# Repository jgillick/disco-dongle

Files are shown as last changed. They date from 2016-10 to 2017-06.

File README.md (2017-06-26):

# Disco Dongle

Open Source Hardware (http://www.oshwa.org/)

A USB to RS485 dongle uniquely designed for [Disco Bus](https://github.com/jgillick/Disco-Bus-Protocol)
networks, however, can be used for many other multidrop needs.

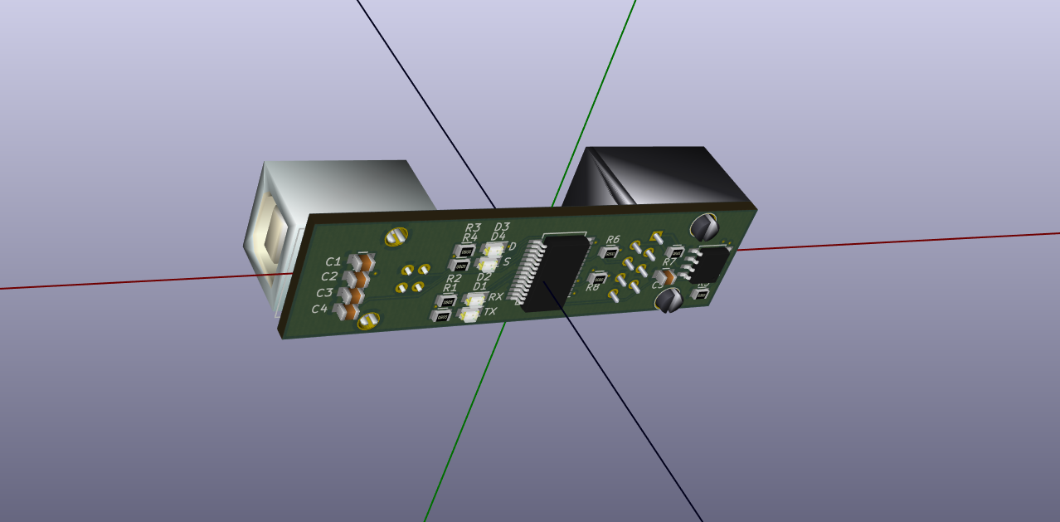
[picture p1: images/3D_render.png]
3D Rendering


## About

This is a basic FTDI to RS485 device, that will connect your computer to a multidrop
network via USB. The RTS line is connected to RJ45 jack (ethernet jack) pin 3, and the DSR line is
connected to RJ45 jack pin 4.

If using this on a Disco Bus network, RTS/pin 3 would be to the first node's daisy chain line and
DSR/ping 4 would be on the shared signal line.

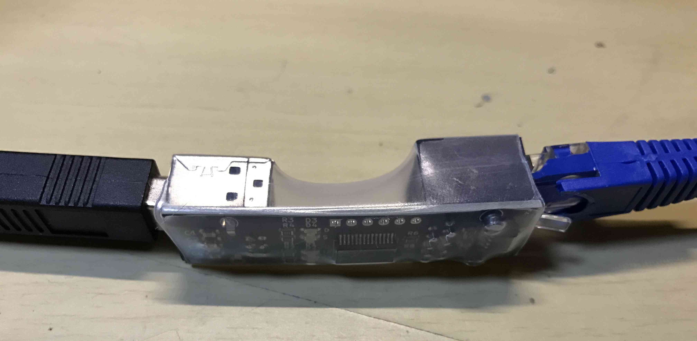
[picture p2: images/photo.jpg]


## Ethernet Pinout

The output of the dongle to the bus, is via a RJ45 ethernet jack.

| RJ45 Pin | Connection |
|---|---|
| 1 | RS485 A/Y |
| 2 | RS485 B/Z |
| 3 | RTS / Daisy |
| 4 | DSR / Signal  |
| 5 | GND |
| 6 | GND |
| 7 | Not connected |
| 8 | Not connected |

### RTS & DSR Lines

The `RTS` and `DSR` serial lines are broken out to RJ45 pins 3 and 4, respectively.
They are pulled up by a pair of 20k resistors, and assumed enabled when driven low.
They also have LEDs used to determine their enabled state. The LED for `RTS` is labeled
"D" (for Daisy) and `DSR` is labeled "S" (for Signal).

## Power over the bus

Since pins 7 and 8 are unused, these can be used to send power to the bus, while
using pins 5 and 6 for ground.

## BOM

| QTY | Designator  | Value | Footprint | Description | Digikey |
|-----|---|---|---|---|---|
| 4 | R1,R2,R4,R3 | 200 | 0805 | Resistor | [RMCF0805JT200RCT-ND](https://www.digikey.com/product-detail/en/stackpole-electronics-inc/RMCF0805JT200R/RMCF0805JT200RCT-ND/1942543) |
| 3 | R5,R6,R8 | 20k | 0805 | Resistor | [311-20KARCT-ND](https://www.digikey.com/product-detail/en/yageo/RC0805JR-0720KL/311-20KARCT-ND/731229) |
| 1 | R7 | 120 | 0805 | Resistor | [RMCF0805JT120R](http://www.digikey.com/product-detail/en/stackpole-electronics-inc/RMCF0805JT120R/RMCF0805JT120RCT-ND/1942540) |
| 3 | C1,C4,C5 | 100nF | 0805 | Capacitor | [1276-2450-1-ND](http://www.digikey.com/product-detail/en/samsung-electro-mechanics-america-inc/CL21B104MBCNNNC/1276-2450-1-ND/3890536) |
| 1 | C2 | 4.7uF | 0805 | Capacitor | [1276-6463-1-ND](http://www.digikey.com/product-detail/en/samsung-electro-mechanics-america-inc/CL21A475KOFNNNG/1276-6463-1-ND/5958091)|
| 1 | C3 | 10nF | 0805 | Capacitor | [1276-2434-1-ND](http://www.digikey.com/product-detail/en/samsung-electro-mechanics-america-inc/CL21B103KAANNNC/1276-2434-1-ND/3890520) |
| 2 | D1,D2 | | 0805 | TX/RX LEDs | [475-1415-1-ND](http://www.digikey.com/product-detail/en/osram-opto-semiconductors-inc/LH-R974-LP-1/475-1415-1-ND/1802604) |
| 2 | D3,D4 | | 0805 | Daisy/Signal LEDs | [475-1410-1-ND](http://www.digikey.com/product-detail/en/osram-opto-semiconductors-inc/LG-R971-KN-1/475-1410-1-ND/1802598) |
| 1 | U1 | | SSOP-28 | FT232RL | [768-1007-1-ND](http://www.digikey.com/product-detail/en/ftdi-future-technology-devices-international-ltd/FT232RL-REEL/768-1007-1-ND/1836402) |
| 1 | U2 | | SOIC-8 | RS485 Transceiver | [ISL81487EIBZ-TCT-ND](http://www.digikey.com/product-detail/en/intersil/ISL81487EIBZ-T/ISL81487EIBZ-TCT-ND/1034270) |
| 1 | J1 | | | USB - B Micro | [609-4618-1-ND](http://www.digikey.com/product-search/en?keywords=609-4618-1-ND) |
| 1 | J2 | | | RJ45 Jack | [609-1046-ND](http://www.digikey.com/product-search/en?keywords=54602-908LF) |

## Order One

You can either build one yourself, or [MacroFab](http://macrofab.com) will assemble
one for you for ~$30.

To use MacroFab:

 * [Create an account](http://macrofab.com)
 * Create a new PCB
 * Goto the "Design Files" tab.
   * Upload `BOM_MacroFab.xyrs`
   * Upload `Gerbers/*`
 * Goto the "Bill of Materials" tab and Verify all parts are selected/populated (except OSHW-Logo).
 * Goto the "Placement" tab and verify parts are arranged properly.
 * Click "Order Now"

## Credit

 This hardware was adapted from the [original work](https://github.com/cinderblock/DanceDongle)
 by [Cameron Tacklind](https://github.com/cinderblock).

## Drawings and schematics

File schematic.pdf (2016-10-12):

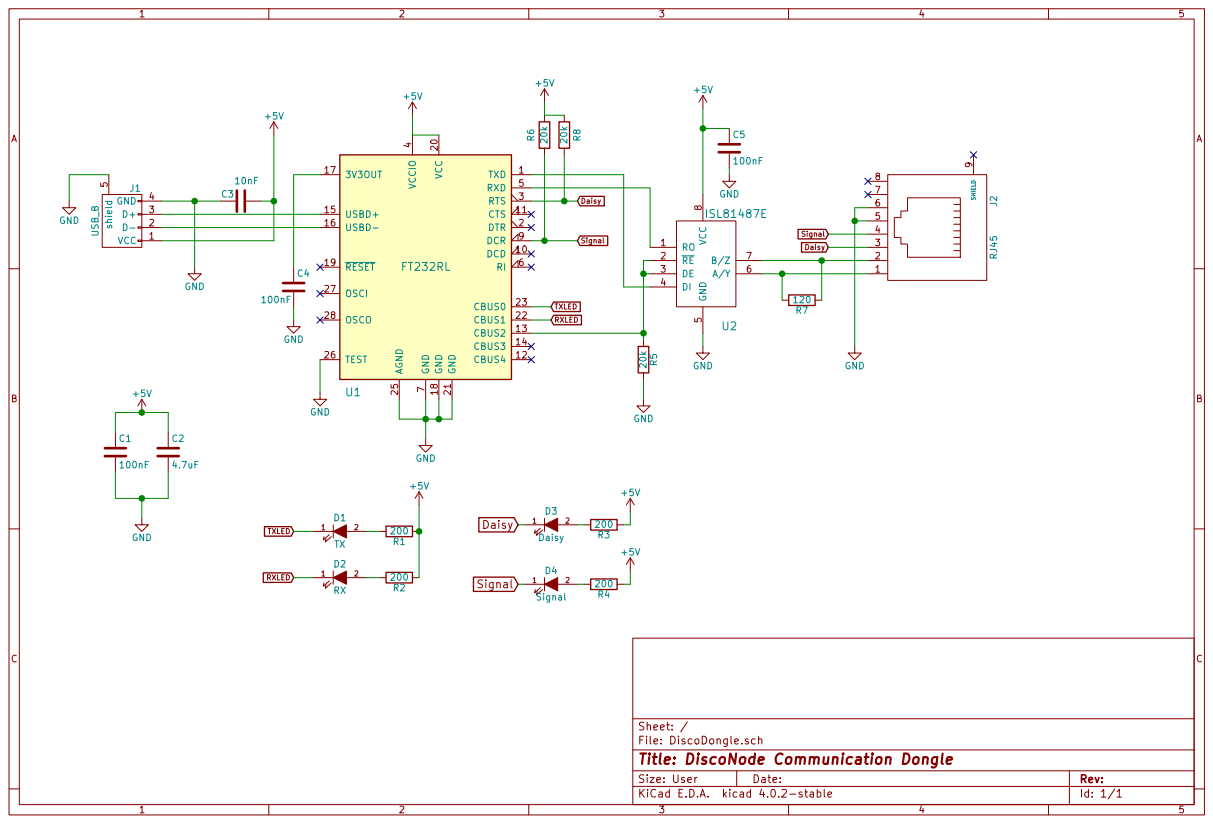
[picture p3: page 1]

7 DCR 9 DCD 10 VCC 20 CTS 11 GND 21 CBUS4 12 CBUS1 22 CBUS2 13 CBUS0 23 CBUS3 14 USBD+ 15 AGND 25 USBD- 16 TEST 26

File: DiscoDongle.sch Sheet: /
Id: 1/1 Title: DiscoNode Communication Dongle

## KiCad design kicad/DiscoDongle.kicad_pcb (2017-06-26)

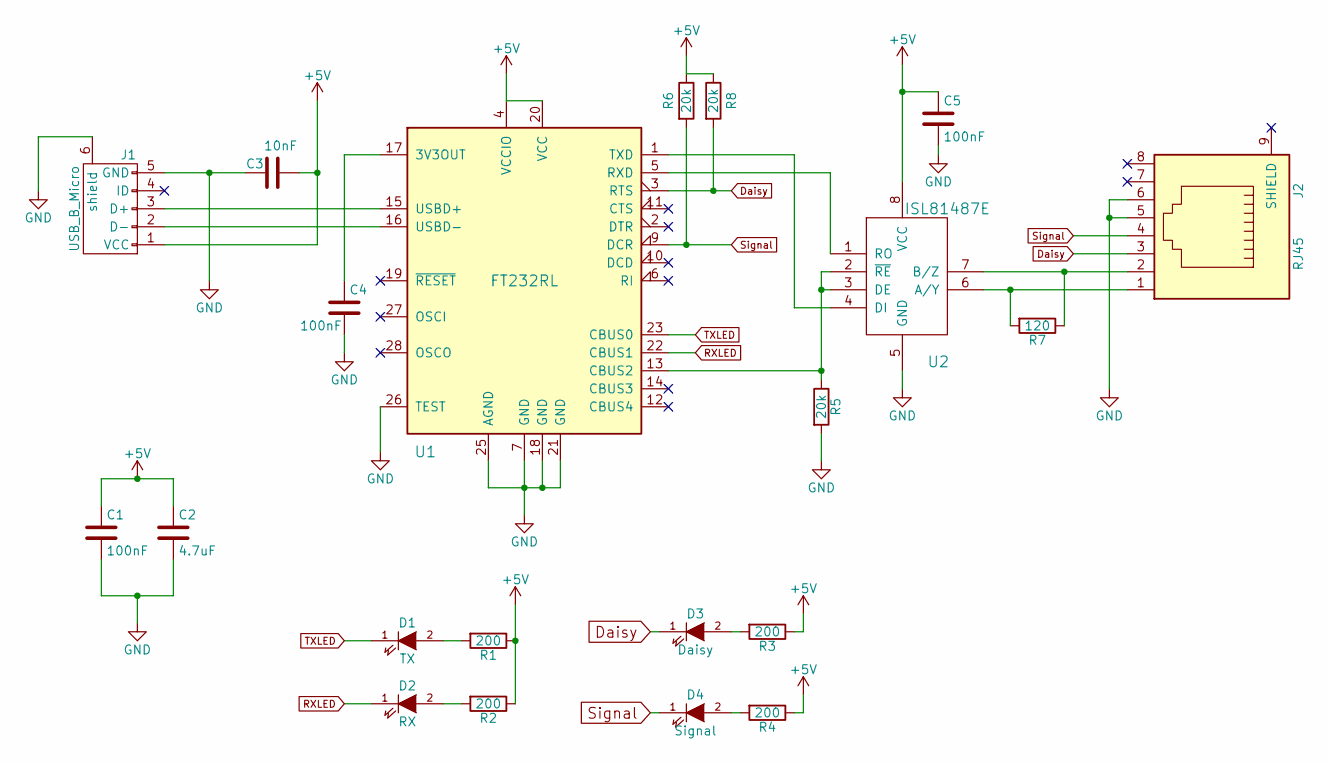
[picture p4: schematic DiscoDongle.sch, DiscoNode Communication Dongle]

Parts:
C1, C4, C5: 100nF; C_0805
C2: 4.7uF; C_0805; MPN CL21A475KOFNNNG; Digikey 1276-6463-1-ND
C3: 10nF; C_0805; MPN CL21B103KAANNNC; Digikey 1276-2434-1-ND
D1: TX; LED_0805; MPN LH R974-LP-1; Digikey 475-1415-1-ND
D2: RX; LED_0805; MPN LH R974-LP-1; Digikey 475-1415-1-ND
D3: Daisy; LED_0805; MPN LG R971-KN-1; Digikey 475-1410-1-ND
D4: Signal; LED_0805; MPN LG R971-KN-1; Digikey 475-1410-1-ND
J1: USB_B_Micro; USB_Micro-B; MPN 10118194-0001LF; Digikey 609-4618-1-ND
J2: RJ45; RJ45_8; MPN 54602-908LF; Digikey 609-1046-ND
R1, R2, R3, R4: 200; R_0805
R5, R6, R8: 20k; R_0805
R7: 120; R_0805; MPN RMCF0805JT120R; Digikey RMCF0805JT120RCT-ND
U1: FT232RL; SSOP-28_5.3x10.2mm_Pitch0.65mm; MPN FT232RL; Digikey 768-1007-1-ND
U2: ISL81487E; SOIC-8_3.9x4.9mm_Pitch1.27mm; Digikey ISL81487EIBZ-TCT-ND

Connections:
+5V: C1.1, C2.1, C3.1, C5.1, J1.1 (VCC), R1.1, R2.1, R3.1, R4.1, R6.1, R8.1, U1.4 (VCCIO), U1.20 (VCC), U2.8 (VCC)
Daisy: D3.1 (K), J2.3, R8.2, U1.3 (RTS)
GND: C1.2, C2.2, C3.2, C4.2, C5.2, J1.5 (GND), J1.6 (shield), J2.5, J2.6, R5.2, U1.7 (GND), U1.18 (GND), U1.21 (GND), U1.25 (AGND), U1.26 (TEST), U2.5 (GND)
unnamed: C4.1, U1.17 (3V3OUT)
unnamed: D1.2 (A), R1.2
unnamed: D2.2 (A), R2.2
unnamed: D3.2 (A), R3.2
unnamed: D4.2 (A), R4.2
unnamed: J1.2 (D-), U1.16 (USBD-)
unnamed: J1.3 (D+), U1.15 (USBD+)
unnamed: J2.1, R7.2, U2.6 (A/Y)
unnamed: J2.2, R7.1, U2.7 (B/Z)
unnamed: R5.1, U1.13 (CBUS2), U2.2 (~RE), U2.3 (DE)
unnamed: U1.1 (TXD), U2.4 (DI)
unnamed: U1.5 (RXD), U2.1 (RO)
RXLED: D2.1 (K), U1.22 (CBUS1)
Signal: D4.1 (K), J2.4, R6.2, U1.9 (DCR)
TXLED: D1.1 (K), U1.23 (CBUS0)

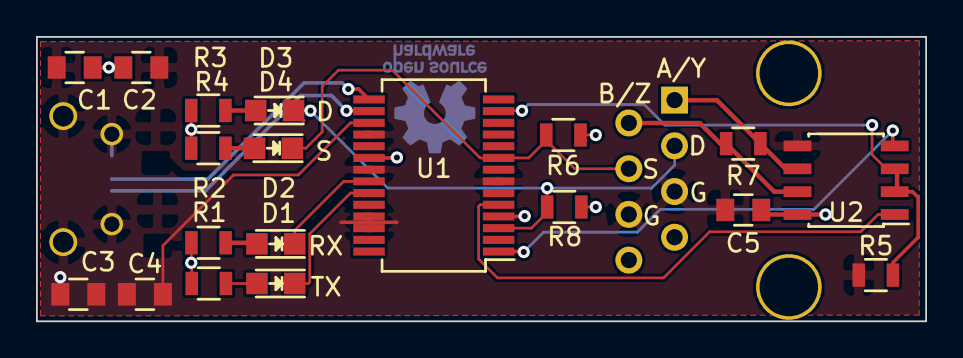
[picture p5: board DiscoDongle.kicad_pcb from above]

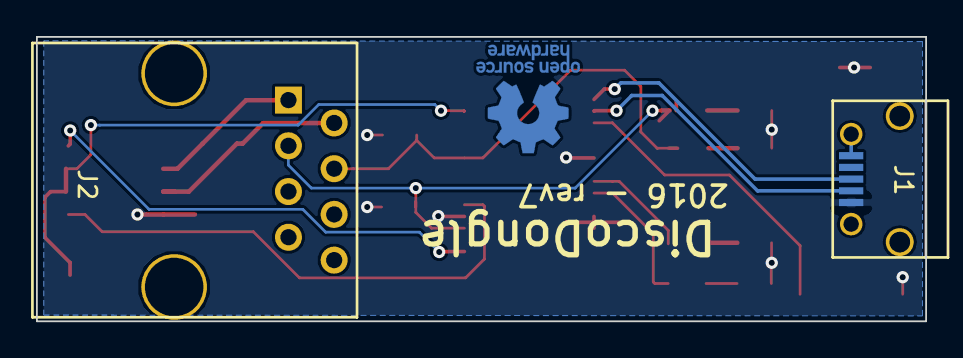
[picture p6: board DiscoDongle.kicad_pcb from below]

Board: 2 copper layers, 49.4 x 15.8 mm, 21 parts (2 on the bottom side), 18 nets.

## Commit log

2016-10-12 Rename board
    [DiscoDongle-B.Cu.gbl, DiscoDongle-B.Mask.gbs, DiscoDongle-B.SilkS.gbo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]
2016-10-22 Change USB to micro-B. Add part numbers
    [DiscoDongle-B.Cu.gbl, DiscoDongle-B.Mask.gbs, DiscoDongle-B.SilkS.gbo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]
2017-06-26 Micro USB
    [DiscoDongle-B.Cu.gbl, DiscoDongle-B.Mask.gbs, DiscoDongle-B.SilkS.gbo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]
